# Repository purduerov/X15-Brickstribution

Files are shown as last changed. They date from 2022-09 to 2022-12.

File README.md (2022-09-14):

# Readme for X15-Brickstribution

Whenever you make a new part, download the datasheet and save it here _**and**_ with the part in the parts library

Always pull other people's changes before beginning to work
`git pull`

Be sure to push your changes after  working on them. Run:
1. `git add .` to add any files in this directory or a subdirectory
or `git add -u` to add any modified files
2. (Optional) `git clean -nX` to see what ignored files can be removed
	`git clean -fX` removes ignored files (Eagle backups)
3. `git commit -m "helpful commit message"` with a description of the work that you did
4. `git push` to push your work to github

Other helpful commands
* `git status` says information about modified and staged files
* `git log` shows the recent commits of the repository
* `git log filename.extension` show the recent commits for just that file
* `git checkout first-couple-letter-of-commit-id` lets you go back to a previous version
* `git checkout master` brings you back to the latest commit
* `git tag` lists the tags
* `git tag -a orderX -m "the version of the board placed for the X'th order"` tag a specific commit
* `git push --tags` needed to push tags to remote
* `git show orderX` show the commit log for the given tag
* `git checkout orderX` go back and interact with the files at the tagged commit

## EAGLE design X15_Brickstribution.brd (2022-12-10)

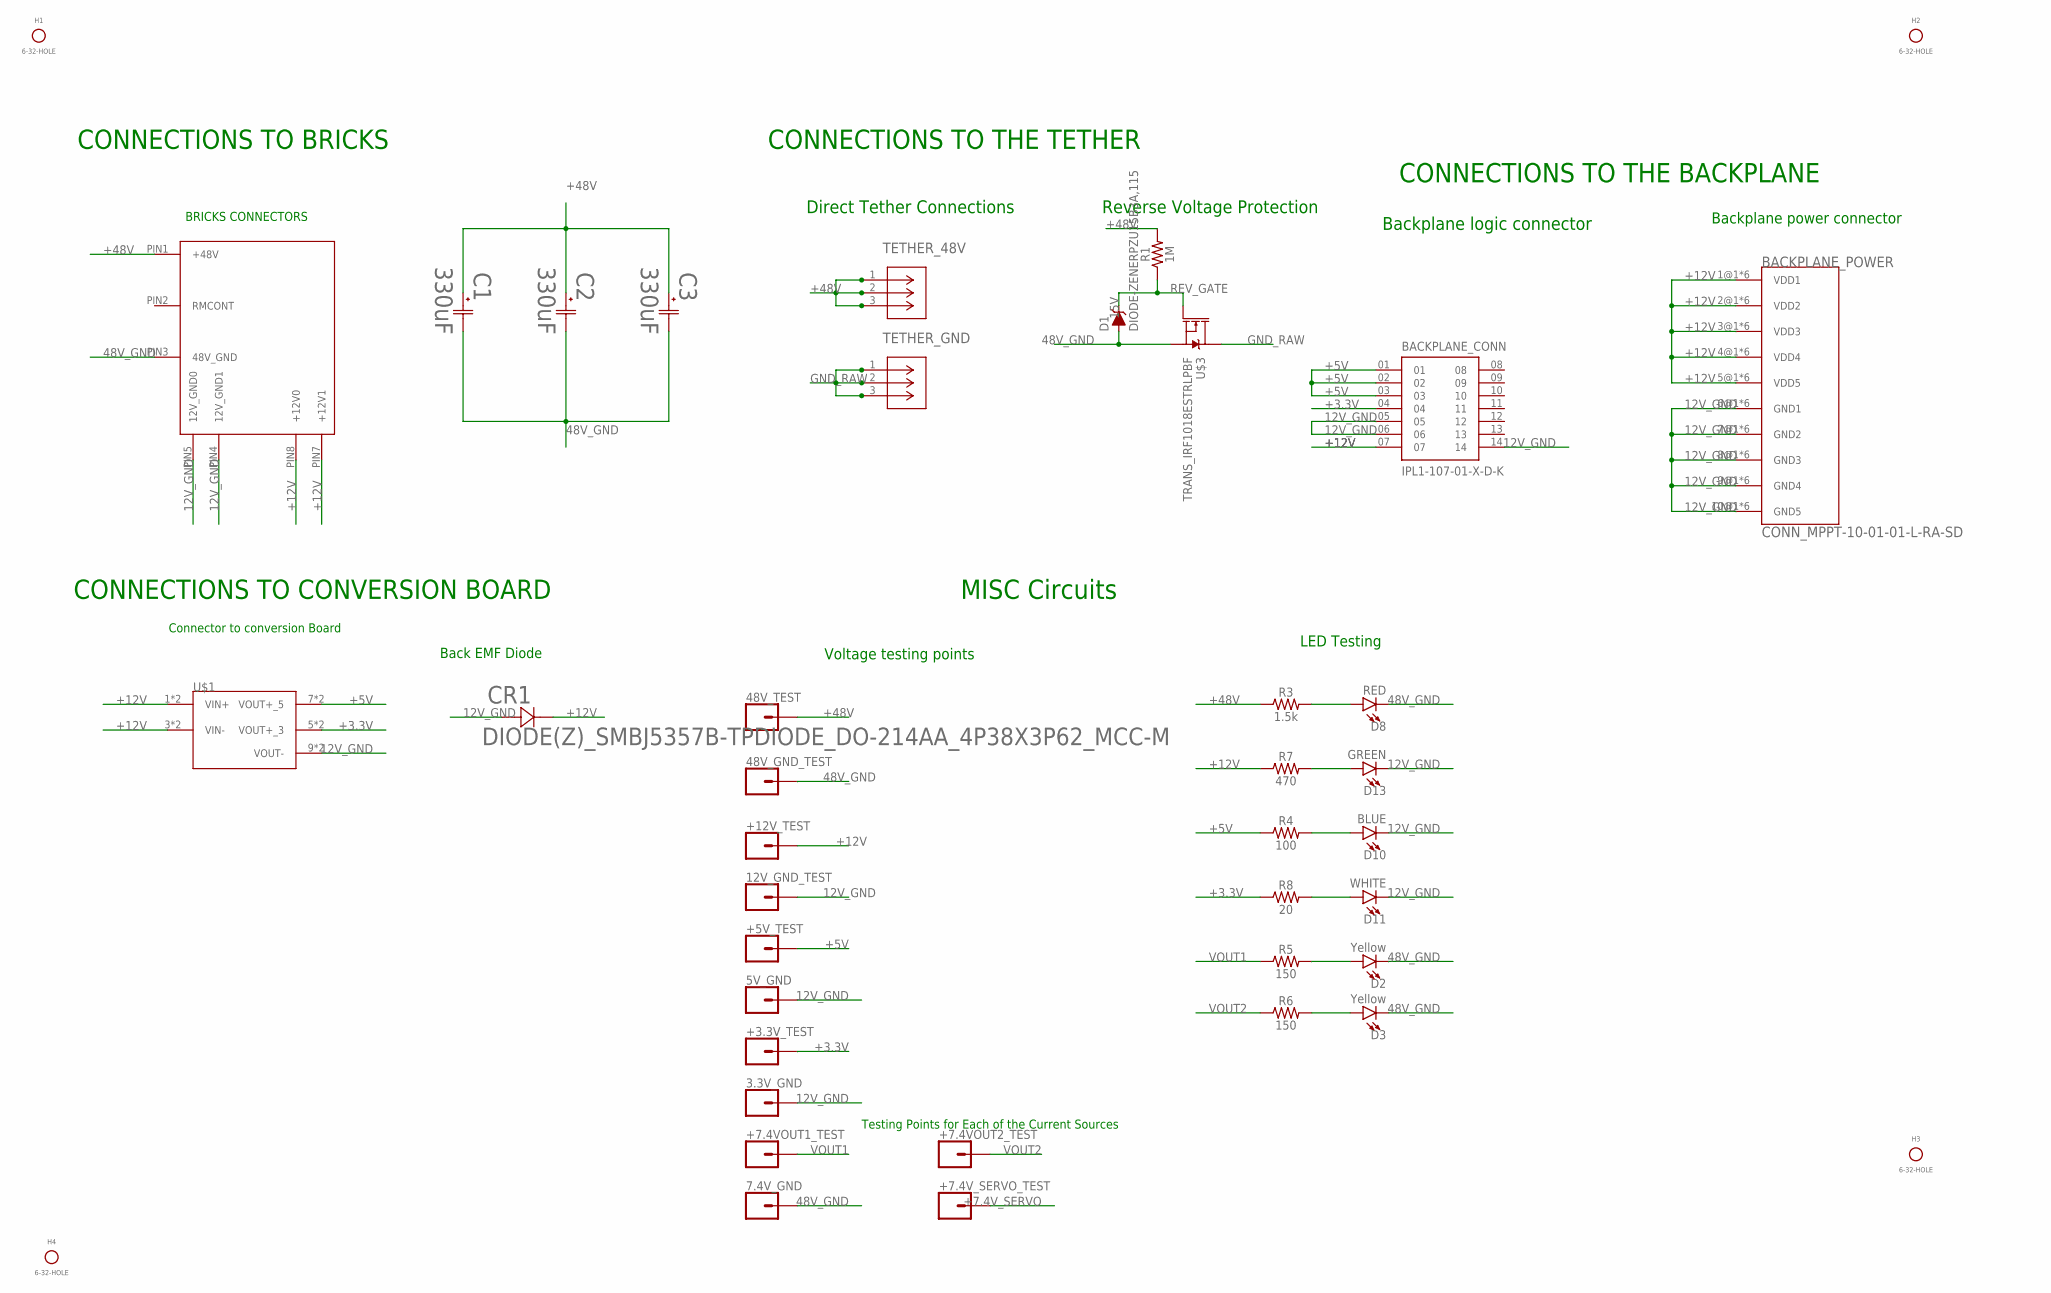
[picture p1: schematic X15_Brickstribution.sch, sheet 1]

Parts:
3.3V_GND, 5V_GND, 7.4V_GND, 12V_GND_TEST, 48V_GND_TEST, 48V_TEST: CONN_01; 1X01
+3.3V_TEST, +5V_TEST, +7.4VOUT1_TEST, +7.4VOUT2_TEST, +7.4V_SERVO_TEST, +12V_TEST: CONN_01; 1X01
BACKPLANE_CONN: IPL1-107-01-X-D-K; SAMTEC_IPL1-107-01-X-D-K
BACKPLANE_POWER: CONN_MPPT-10-01-01-L-RA-SD; MPPT-10-01-01-L-RA-SD
C1, C2, C3: 330uF; CAP_099112E3_VIS-M
CR1: DIODE(Z)_SMBJ5357B-TPDIODE_DO-214AA_4P38X3P62_MCC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; DIODE_DO-214AA_4P38X3P62_MCC-M
D1: DIODE-ZENERPZU15B3A,115; SOD-323
D2, D3: Yellow; LED-0603
D8: RED; LED-0603
D10: BLUE; LED-0603
D11: WHITE; LED-0603
D13: GREEN; LED-0603
H1, H2, H3, H4: 6-32-HOLE
R1: 1M; 0603
R3: 1.5k; 0603
R4: 100; 0603
R5, R6: 150; 0603
R7: 470; 0603
R8: 20; 0603
TETHER_48V: 796636-3(TETHER); CON3_P5MM_VER_TERM-BLK_TYC
TETHER_GND: 796636-3(TETHER); CON3_P5MM_VER_TERM-BLK_TYC
U$1: CONN_DISTRIBUTION_TO_CONVERSION; TSW-105-05-G-S(D-C)
U$2: CONN_BMR480_CONNECTOR; BMR480_CONNECTOR
U$3: TRANS_IRF1018ESTRLPBF; D2PAK

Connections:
12V_GND: 3.3V_GND.1, 5V_GND.1, 12V_GND_TEST.1, BACKPLANE_CONN.05, BACKPLANE_CONN.06, BACKPLANE_CONN.14, BACKPLANE_POWER.6@1 (GND1), BACKPLANE_POWER.6@2 (GND1), BACKPLANE_POWER.6@3 (GND1), BACKPLANE_POWER.6@4 (GND1), BACKPLANE_POWER.6@5 (GND1), BACKPLANE_POWER.6@6 (GND1), BACKPLANE_POWER.7@1 (GND2), BACKPLANE_POWER.7@2 (GND2), BACKPLANE_POWER.7@3 (GND2), BACKPLANE_POWER.7@4 (GND2), BACKPLANE_POWER.7@5 (GND2), BACKPLANE_POWER.7@6 (GND2), BACKPLANE_POWER.8@1 (GND3), BACKPLANE_POWER.8@2 (GND3), BACKPLANE_POWER.8@3 (GND3), BACKPLANE_POWER.8@4 (GND3), BACKPLANE_POWER.8@5 (GND3), BACKPLANE_POWER.8@6 (GND3), BACKPLANE_POWER.9@1 (GND4), BACKPLANE_POWER.9@2 (GND4), BACKPLANE_POWER.9@3 (GND4), BACKPLANE_POWER.9@4 (GND4), BACKPLANE_POWER.9@5 (GND4), BACKPLANE_POWER.9@6 (GND4), BACKPLANE_POWER.10@1 (GND5), BACKPLANE_POWER.10@2 (GND5), BACKPLANE_POWER.10@3 (GND5), BACKPLANE_POWER.10@4 (GND5), BACKPLANE_POWER.10@5 (GND5), BACKPLANE_POWER.10@6 (GND5), CR1.2, D10.C, D11.C, D13.C, U$1.9 (VOUT-), U$1.10 (VOUT-), U$2.PIN4 (12V_GND1), U$2.PIN5 (12V_GND0)
48V_GND: 7.4V_GND.1, 48V_GND_TEST.1, C1.2, C2.2, C3.2, D1.A, D2.C, D3.C, D8.C, U$2.PIN3 (48V_GND), U$3.2 (S); also elsewhere on the board
+3.3V: +3.3V_TEST.1, BACKPLANE_CONN.04, R8.1, U$1.5 (VOUT+_3), U$1.6 (VOUT+_3)
+5V: +5V_TEST.1, BACKPLANE_CONN.01, BACKPLANE_CONN.02, BACKPLANE_CONN.03, R4.1, U$1.7 (VOUT+_5), U$1.8 (VOUT+_5)
+7.4V_SERVO: +7.4V_SERVO_TEST.1; also elsewhere on the board
+12V: +12V_TEST.1, BACKPLANE_CONN.07, BACKPLANE_POWER.1@1 (VDD1), BACKPLANE_POWER.1@2 (VDD1), BACKPLANE_POWER.1@3 (VDD1), BACKPLANE_POWER.1@4 (VDD1), BACKPLANE_POWER.1@5 (VDD1), BACKPLANE_POWER.1@6 (VDD1), BACKPLANE_POWER.2@1 (VDD2), BACKPLANE_POWER.2@2 (VDD2), BACKPLANE_POWER.2@3 (VDD2), BACKPLANE_POWER.2@4 (VDD2), BACKPLANE_POWER.2@5 (VDD2), BACKPLANE_POWER.2@6 (VDD2), BACKPLANE_POWER.3@1 (VDD3), BACKPLANE_POWER.3@2 (VDD3), BACKPLANE_POWER.3@3 (VDD3), BACKPLANE_POWER.3@4 (VDD3), BACKPLANE_POWER.3@5 (VDD3), BACKPLANE_POWER.3@6 (VDD3), BACKPLANE_POWER.4@1 (VDD4), BACKPLANE_POWER.4@2 (VDD4), BACKPLANE_POWER.4@3 (VDD4), BACKPLANE_POWER.4@4 (VDD4), BACKPLANE_POWER.4@5 (VDD4), BACKPLANE_POWER.4@6 (VDD4), BACKPLANE_POWER.5@1 (VDD5), BACKPLANE_POWER.5@2 (VDD5), BACKPLANE_POWER.5@3 (VDD5), BACKPLANE_POWER.5@4 (VDD5), BACKPLANE_POWER.5@5 (VDD5), BACKPLANE_POWER.5@6 (VDD5), CR1.1, R7.1, U$1.1 (VIN+), U$1.2 (VIN+), U$1.3 (VIN-), U$1.4 (VIN-), U$2.PIN7 (+12V1), U$2.PIN8 (+12V0)
+48V: 48V_TEST.1, C1.1, C2.1, C3.1, R1.2, R3.1, TETHER_48V.1, TETHER_48V.2, TETHER_48V.3, U$2.PIN1 (+48V); also elsewhere on the board
GND_RAW: TETHER_GND.1, TETHER_GND.2, TETHER_GND.3, U$3.3 (D)
unnamed: D8.A, R3.2
unnamed: D10.A, R4.2
unnamed: D11.A, R8.2
unnamed: D3.A, R6.2
unnamed: D2.A, R5.2
unnamed: D13.A, R7.2
REV_GATE: D1.C, R1.1, U$3.1 (G)
VOUT1: +7.4VOUT1_TEST.1, R5.1; also elsewhere on the board
VOUT2: +7.4VOUT2_TEST.1, R6.1; also elsewhere on the board

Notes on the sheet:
CONNECTIONS TO BRICKS
BRICKS CONNECTORS
CONNECTIONS TO CONVERSION BOARD
Back EMF Diode
CONNECTIONS TO THE TETHER
Reverse Voltage Protection
Direct Tether Connections
MISC Circuits
Voltage testing points
Backplane logic connector
Backplane power connector
CONNECTIONS TO THE BACKPLANE
Connector to conversion Board
LED Testing
Testing Points for Each of the Current Sources

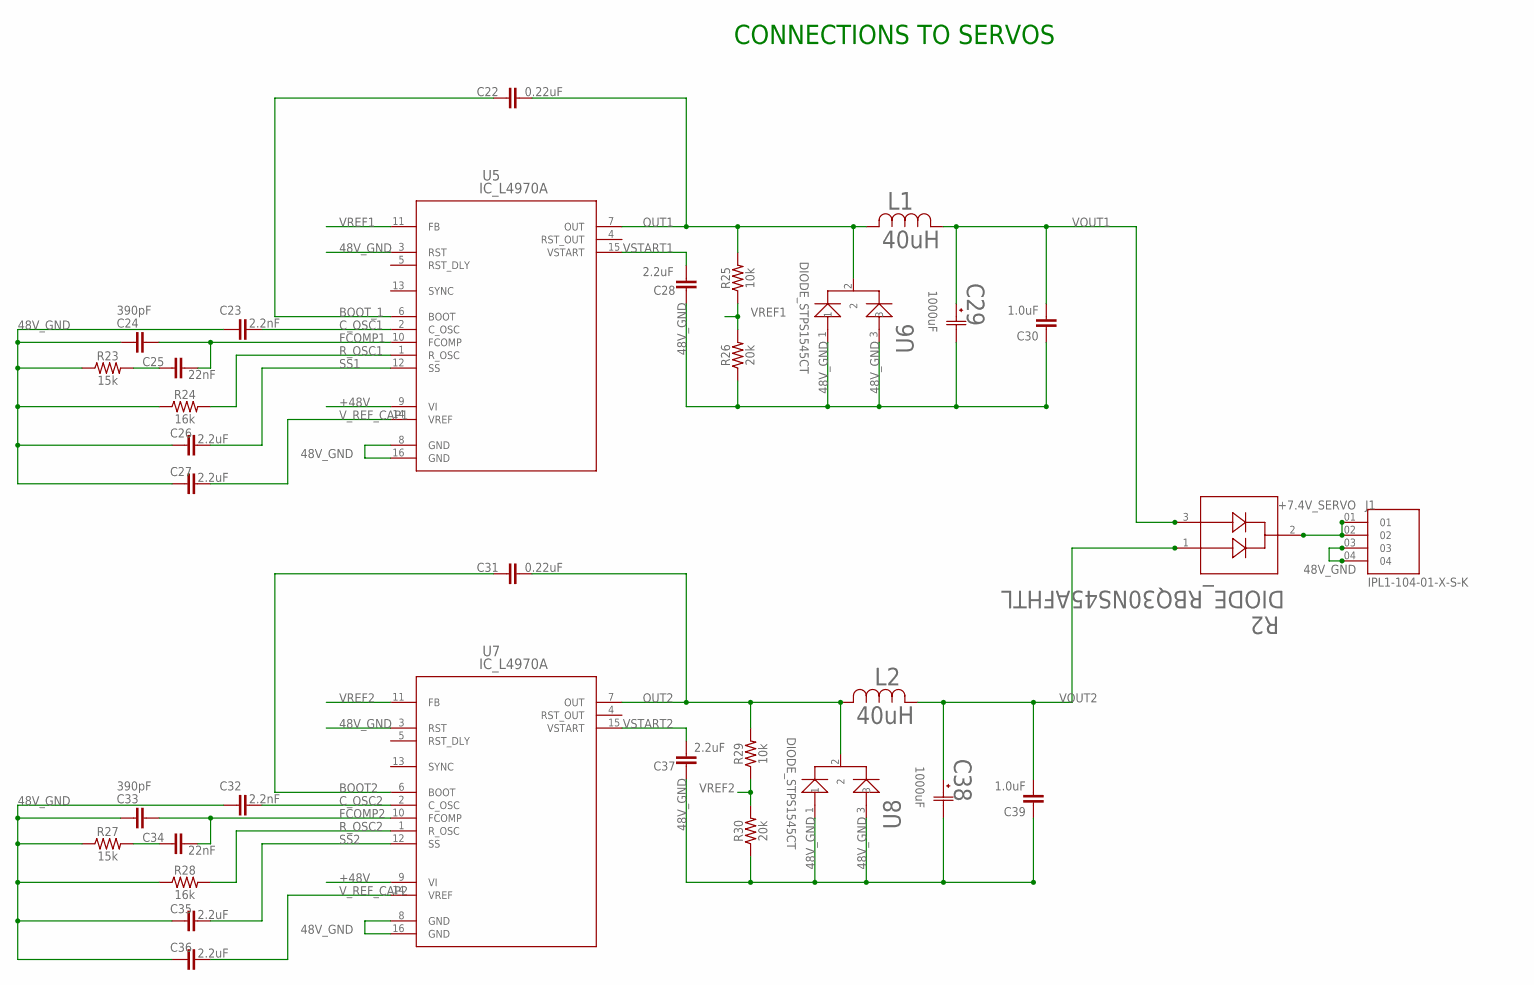
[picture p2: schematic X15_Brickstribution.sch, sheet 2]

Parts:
C22, C31: 0.22uF; 0603
C23, C32: 2.2nF; 0603
C24, C33: 390pF; 0603
C25, C34: 22nF; 0603
C26, C27, C28, C35, C36, C37: 2.2uF; 0603
C29, C38: 1000uF; CAP_PC_10X12P7_NCH-M
C30, C39: 1.0uF; 0603
J1: IPL1-104-01-X-S-K; SAMTEC_IPL1-104-01-X-S-K
L1, L2: 40uH; IND_23XX-V_53_53
R2: DIODE_RBQ30NS45AFHTL; TRANS_R5009FNJ_ROM
R23, R27: 15k; 0603
R24, R28: 16k; 0603
R25, R29: 10k; 0603
R26, R30: 20k; 0603
U5, U7: IC_L4970A; MULTIWATT15_V_STM
U6, U8: DIODE_STPS1545CT; TO-220AB_STM

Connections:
48V_GND: C23.1, C24.1, C26.1, C27.1, C28.1, C29.2, C30.1, C32.1, C33.1, C35.1, C36.1, C37.1, C38.2, C39.1, J1.03, J1.04, R23.1, R24.1, R26.1, R27.1, R28.1, R30.1, U5.3 (RST), U5.8 (GND), U5.16 (GND), U6.1, U6.3, U7.3 (RST), U7.8 (GND), U7.16 (GND), U8.1, U8.3; also elsewhere on the board
+7.4V_SERVO: J1.01, J1.02, R2.2; also elsewhere on the board
+48V: U5.9 (VI), U7.9 (VI); also elsewhere on the board
BOOT2: C31.1, U7.6 (BOOT)
BOOT_1: C22.1, U5.6 (BOOT)
C_OSC1: C23.2, U5.2 (C_OSC)
C_OSC2: C32.2, U7.2 (C_OSC)
FCOMP1: C24.2, C25.2, U5.10 (FCOMP)
FCOMP2: C33.2, C34.2, U7.10 (FCOMP)
unnamed: C25.1, R23.2
unnamed: C34.1, R27.2
OUT1: C22.2, L1.2, R25.2, U5.7 (OUT), U6.2
OUT2: C31.2, L2.2, R29.2, U7.7 (OUT), U8.2
R_OSC1: R24.2, U5.1 (R_OSC)
R_OSC2: R28.2, U7.1 (R_OSC)
SS1: C26.2, U5.12 (SS)
SS2: C35.2, U7.12 (SS)
VOUT1: C29.1, C30.2, L1.1, R2.3; also elsewhere on the board
VOUT2: C38.1, C39.2, L2.1, R2.1; also elsewhere on the board
VREF1: R25.1, R26.2, U5.11 (FB)
VREF2: R29.1, R30.2, U7.11 (FB)
VSTART1: C28.2, U5.15 (VSTART)
VSTART2: C37.2, U7.15 (VSTART)
V_REF_CAP1: C27.2, U5.14 (VREF)
V_REF_CAP2: C36.2, U7.14 (VREF)

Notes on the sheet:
CONNECTIONS TO SERVOS

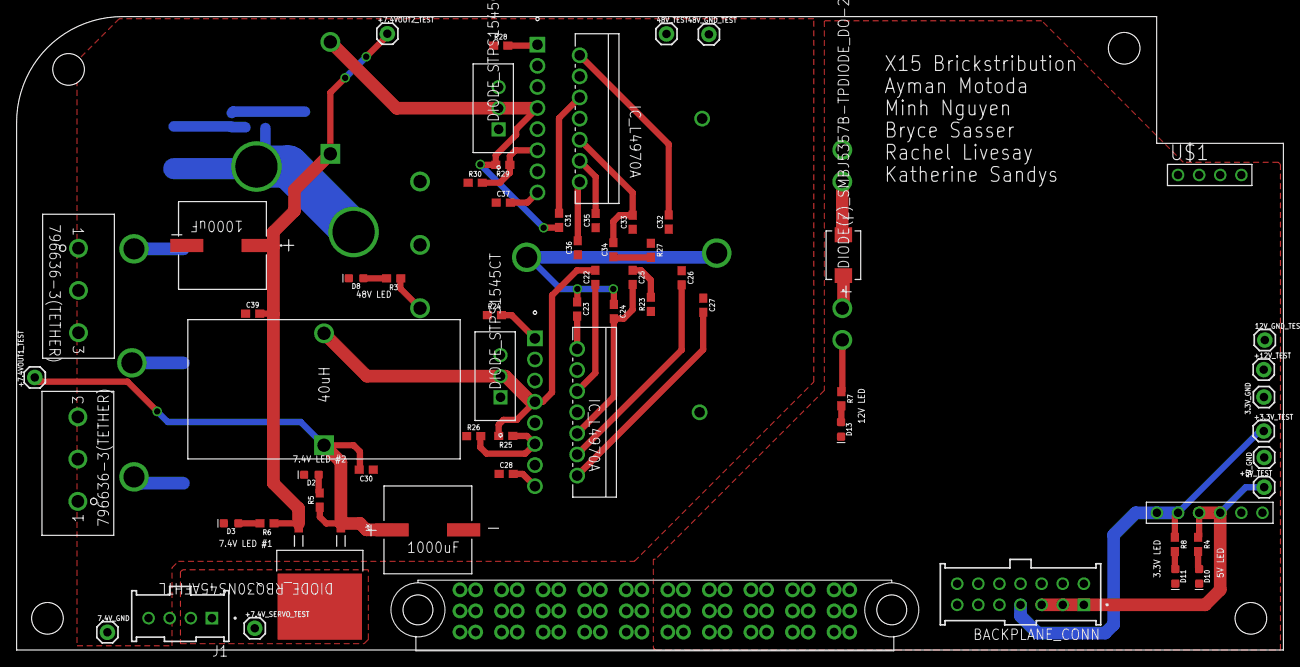
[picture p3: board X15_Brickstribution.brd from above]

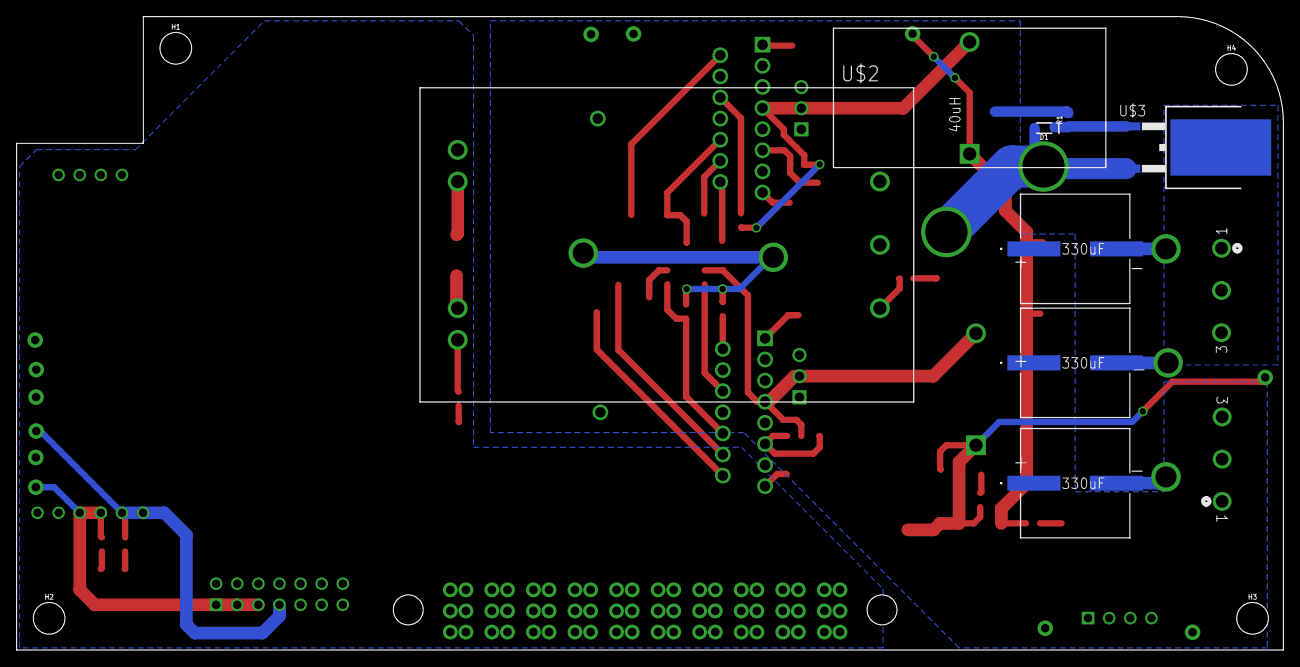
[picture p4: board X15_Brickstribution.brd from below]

Board: 2 copper layers, 152.4 x 76.2 mm, 75 parts (12 on the bottom side), 37 nets.

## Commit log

2022-10-08 git commit -a
    [X15_Brickstribution.brd, X15_Brickstribution.sch]
2022-10-08 Schematic V1
2022-10-08 Schematic V1 - Added Backplane Connections
    [X15_Brickstribution.brd, X15_Brickstribution.sch]
2022-10-15 Schematic Revision V1
    [X15_Brickstribution.brd, X15_Brickstribution.sch]
2022-10-19 Cleaned all backup files and updated schematic for revisions v1
    [X15_Brickstribution.brd, X15_Brickstribution.sch]
2022-10-20 Revision V3 Schematic - LED's added for current source
    [X15_Brickstribution.brd, X15_Brickstribution.sch]
2022-10-20 board dimensions
    [X15_Brickstribution.brd]
2022-10-22 48V Components Added to PCB
    [X15_Brickstribution.brd, X15_Brickstribution.sch]
2022-11-05 Board & Schematic Review Iteration
    [X15_Brickstribution.brd, X15_Brickstribution.sch]
2022-11-09 Changed inductor out and reconfigured traces.
    [X15_Brickstribution.brd, X15_Brickstribution.sch]
2022-11-10 Moved placement of resistors.
    [X15_Brickstribution.brd]
2022-11-12 Changed polygons and connections to reference voltage
    [X15_Brickstribution.brd, X15_Brickstribution.sch]
2022-11-17 Before getting absolutely torn apart by Alumni Review
    [X15_Brickstribution.brd]
2022-12-01 In progress board
    [X15_Brickstribution.brd, X15_Brickstribution.sch]
2022-12-01 Finished version of alternative layout
    [X15_Brickstribution.brd]
2022-12-03 Alumni Revisions Implemented
    [X15_Brickstribution.brd, X15_Brickstribution.sch]
2022-12-03 Fixed Tracing Errors
    [X15_Brickstribution.brd]
2022-12-08 Final Iteration of Layout
    [X15_Brickstribution.brd, X15_Brickstribution.sch]
2022-12-08 Grant Approval
    [X15_Brickstribution.brd]
2022-12-10 Revision before implementing Samtec Brick Connectors
    [X15_Brickstribution.brd, X15_Brickstribution.sch]
2023-01-07 Fixed a small wire stub to pass DRC

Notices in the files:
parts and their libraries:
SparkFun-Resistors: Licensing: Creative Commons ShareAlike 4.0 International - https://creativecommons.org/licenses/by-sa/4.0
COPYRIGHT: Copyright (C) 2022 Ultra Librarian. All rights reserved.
